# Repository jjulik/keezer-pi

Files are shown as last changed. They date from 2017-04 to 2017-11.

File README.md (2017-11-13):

# keezer-pi
Client/Server code for building a Keezer with a Raspberry Pi

## Complete setup guide
Download the raspbian lite image and put it on a micro SD card.

### Configure keyboard (and enable SSH)
`sudo raspi-config`

### Set the machine name
`sudo vi /etc/hosts`
`sudo vi /etc/hostname`

### Backup your wpa_supplicant
`sudo cp /etc/wpa_supplicant/wpa_supplicant.conf ~/wpa_supplicant.conf.bac`

### Connect to Wi-Fi
`wpa_passphrase "network_name" "passphrase" | sudo tee -a /etc/wpa_supplicant/wpa_supplicant.conf > /dev/null`

Then go edit the wpa_supplicant.conf to not have the password

`wpa_cli -i wlan0 reconfigure`

Check with

`ifconfig wlan0`

### Configure Wi-Fi to connect on boot
Set interface wlan0 in dhcpcd.conf

### Update Pi
`sudo apt-get update`
`sudo apt-get upgrade`

### Enable 1 wire interface
Edit /boot/config.txt

Add dtoverlay=w1-gpio

Then reboot the pi

`sudo shutdown -r -t 0`

### Install vim, git, and pip
`sudo apt-get install vim, git, pip`

### Clone the repo
`git clone https://github.com/jjulik/keezer-pi.git`

### Configure keezer-pi
Copy the keezer-pi.config.example to keezer-pi.config

Then edit the settings

### Install keezer-pi
`sudo ./install.sh`

Reboot the pi once more

`sudo shutdown -r -t 0`

And everything should be working correctly now

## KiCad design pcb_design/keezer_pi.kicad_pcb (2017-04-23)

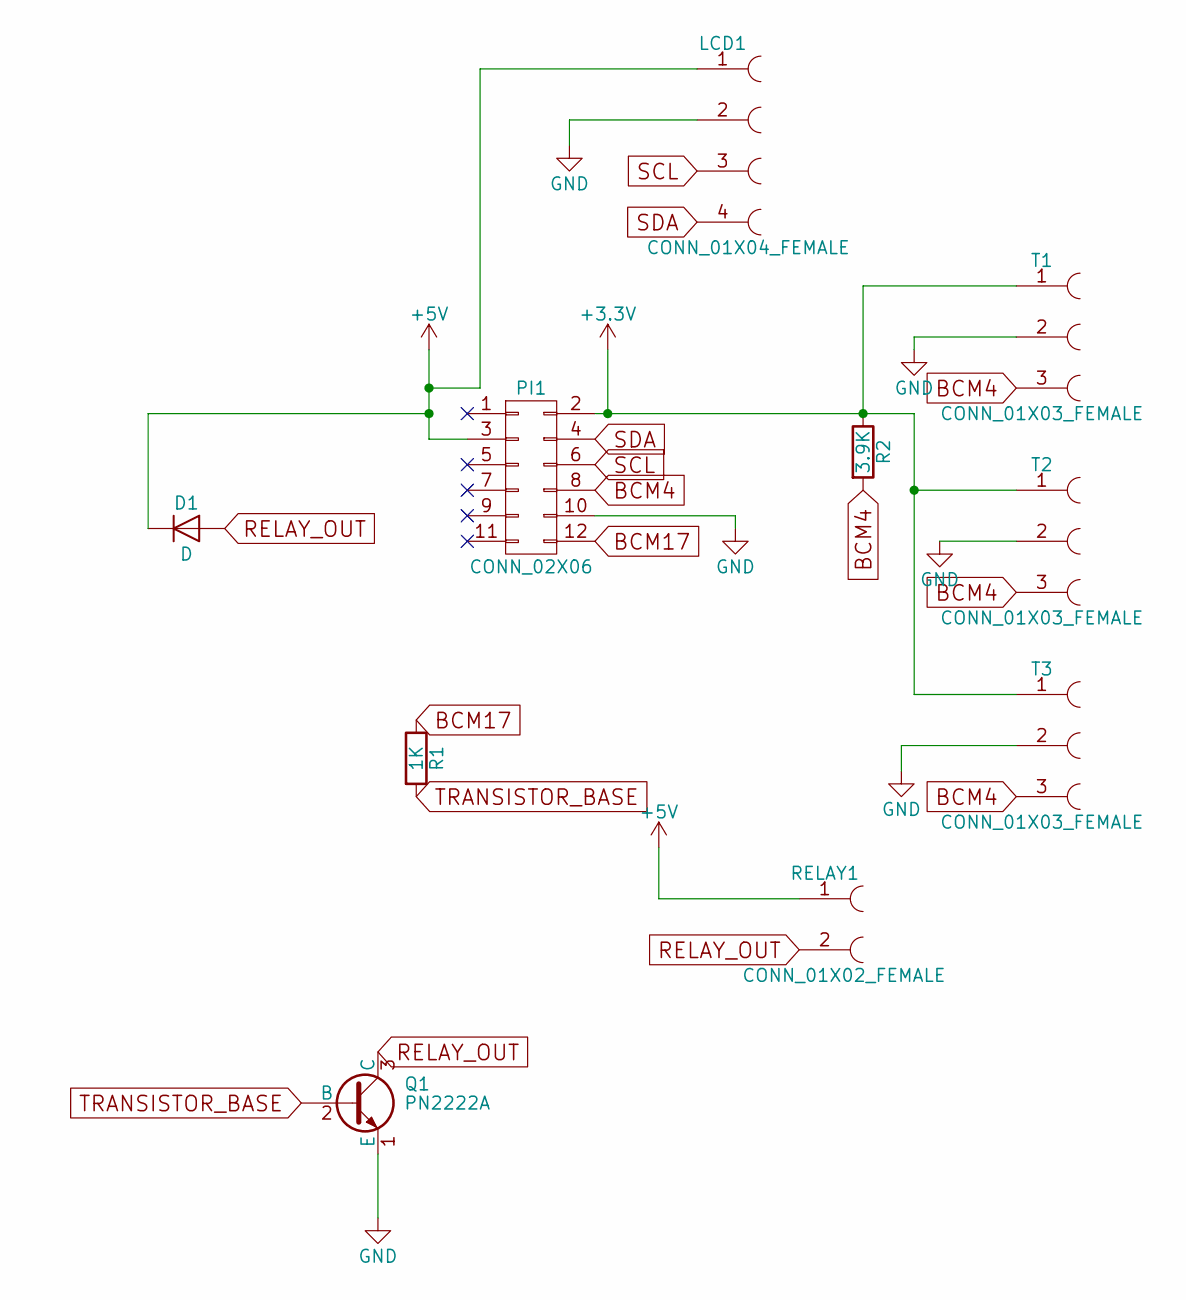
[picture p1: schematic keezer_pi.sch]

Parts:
D1: D; D_DO-41_SOD81_P7.62mm_Horizontal
LCD1: CONN_01X04_FEMALE; Socket_Strip_Angled_1x04_Pitch2.54mm
PI1: CONN_02X06; Pin_Header_Straight_2x06_Pitch2.54mm
Q1: PN2222A; TO-92_Inline_Wide
R1: 1K; R_Axial_DIN0207_L6.3mm_D2.5mm_P7.62mm_Horizontal
R2: 3.9K; R_Axial_DIN0207_L6.3mm_D2.5mm_P7.62mm_Horizontal
RELAY1: CONN_01X02_FEMALE; Socket_Strip_Angled_1x02_Pitch2.54mm
T1, T2, T3: CONN_01X03_FEMALE; Socket_Strip_Angled_1x03_Pitch2.54mm

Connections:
+3V3: PI1.2, R2.1, T1.1, T2.1, T3.1
+5V: D1.1 (K), LCD1.1, PI1.3, RELAY1.1
BCM4: PI1.8, R2.2, T1.3, T2.3, T3.3
BCM17: PI1.12, R1.1
GND: LCD1.2, PI1.10, Q1.1 (E), T1.2, T2.2, T3.2
RELAY_OUT: D1.2 (A), Q1.3 (C), RELAY1.2
SCL: LCD1.3, PI1.6
SDA: LCD1.4, PI1.4
TRANSISTOR_BASE: Q1.2 (B), R1.2

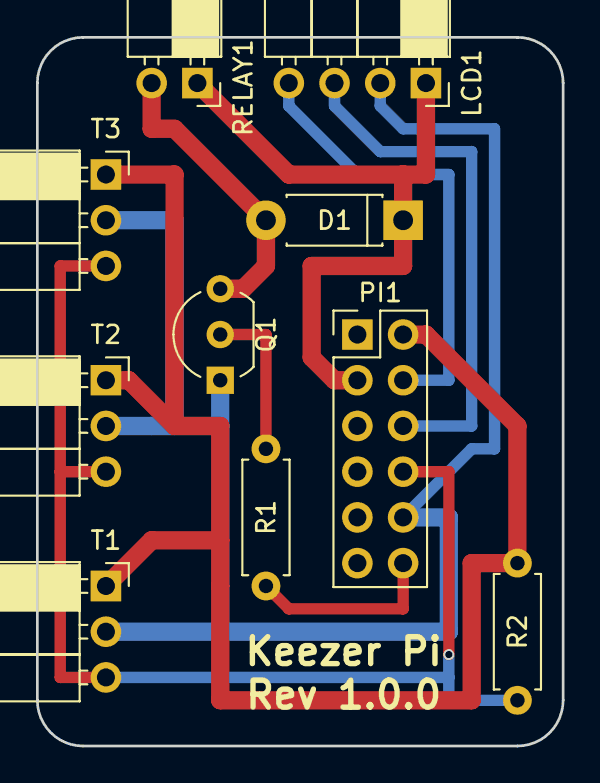
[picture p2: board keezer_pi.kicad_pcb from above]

Board: 2 copper layers, 29.2 x 39.4 mm, 10 parts (0 on the bottom side), 9 nets.

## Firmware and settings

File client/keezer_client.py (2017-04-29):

import os
import time
import json
import logging
import requests
import traceback
import time
import ConfigParser
import io
import threading
import RPi.GPIO as GPIO

# The primary sensor will be used for all sensor readings and determines
# whether we need to run the freezer.
# The secondary sensor will be used as a backup if the primary fails
# until the primary comes online again.
config_file = os.environ.get('KEEZER_CLIENT_SETTINGS')
if config_file is None:
	config_file = 'keezer_client.cfg'
with open(config_file, 'r') as f:
	config_text = f.read()
default_config = { 'secondary_temp': None, 'url': None, 'api_token': None, 'temperature': 40.0, 'deviation': 2.0, 'min_runtime': 60, 'cooldown': 300, 'fridge_name': 'fridgey' }
config = ConfigParser.SafeConfigParser(default_config, allow_no_value=True)
config.readfp(io.BytesIO(config_text))
primary_sensor_name = config.get('sensor', 'primary_temp')
secondary_sensor_name = config.get('sensor', 'secondary_temp')
relay_gpio_pin = config.getint('sensor', 'relay_pin')
server_url = config.get('server', 'url')
api_token = config.get('server', 'api_token')
desired_temperature = config.getfloat('fridge', 'temperature')
deviation = config.getfloat('fridge', 'deviation')
min_runtime = config.getint('fridge', 'min_runtime')
cooldown = config.getint('fridge', 'cooldown')
fridge_name = config.get('fridge', 'fridge_name')
max_temperature = desired_temperature + deviation

FORMAT = '%(asctime)-15s %(message)s'
logging.basicConfig(filename='keezer_client.log',level=logging.ERROR,format=FORMAT)
logger = logging.getLogger('keezer_client')

def post_async(url, headers, data):
	try:
		requests.post(url, headers=headers, data=json.dumps(data))
	except Exception:
		# don't log these errors
		# it could fill up the log fast if the server goes down
		return
		

def post_exception(formatted_exception):
	if server_url is None or api_token is None:
		return
	url = server_url + 'api/error'
	headers = { 'Authorization': api_token, 'Content-Type': 'application/json' }
	data = { 'time': time.time(), 'error': formatted_exception }
	# fire and forget
	postErrorThread = threading.Thread(target=post_async, args=(url,headers,data))
	postErrorThread.start()

def post_reading(reading):
	if server_url is None or api_token is None:
		return
	url = server_url + 'api/reading'
	headers = { 'Authorization': api_token, 'Content-Type': 'application/json' }
	data = { 'time': reading.time, 'reading': reading.reading, 'sensorDescription': reading.sensor_name }
	postReadingThread = threading.Thread(target=post_async, args=(url,headers,data))
	postReadingThread.start()

class Reading():
	def __init__(self, sensor_name, reading, reading_time):
		self.sensor_name = sensor_name
		self.reading = reading
		self.time = reading_time

# Inherit from dictionary for easy JSON serialization.
class Sensor(dict):
	def __init__(self, name):
		self.file_name = '/sys/bus/w1/devices/' + name + '/w1_slave' 
		dict.__init__(self, name=name, file_name=self.file_name)
		self.name = name

	def get_reading(self):
		try:
			f = open(self.file_name, 'r')
			lines = f.readlines()
			reading_time = time.time()
			equals_pos = lines[1].find('t=')
			if equals_pos != -1:
				raw_temp = float(lines[1][equals_pos+2:])
				#murica
				temp_f = (raw_temp / 1000.0) * 9.0 / 5.0 + 32.0
				return Reading(self.name, temp_f, reading_time)
		except Exception:
			logger.exception('Error reading sensor value for {0}'.format(self.name))
			post_exception(traceback.format_exc())
		return None

os.system('modprobe w1-gpio')
os.system('modprobe w1-therm')
primary_sensor = Sensor(primary_sensor_name)
secondary_sensor = None
if secondary_sensor_name is not None:
	secondary_sensor = Sensor(secondary_sensor_name)

try:
	# setup gpio pin for relay
	# we are using BCM numbering
	GPIO.setmode(GPIO.BCM)
	GPIO.setup(relay_gpio_pin, GPIO.OUT)
	GPIO.output(relay_gpio_pin, False)

	# keep track of when the fridge was last turned on or off
	# we don't want to be turning it on/off frequently
	fridge_turned_on = 0
	fridge_turned_off = 0
	fridge_enabled = False
	while True:
		primary_reading = primary_sensor.get_reading()
		secondary_reading = None
		if secondary_sensor is not None:
			secondary_reading = secondary_sensor.get_reading()
			
		if primary_reading is not None:
			post_reading(primary_reading)
		if secondary_reading is not None:
			post_reading(secondary_reading)
		
		reading_to_use = primary_reading
		if reading_to_use is None:
			reading_to_use = secondary_reading
		if reading_to_use is None and fridge_enabled:
			GPIO.output(relay_gpio_pin, False)
			fridge_enabled = False
			fridge_turned_off = time.time()
			power_reading = Reading(fridge_name, 0, fridge_turned_off)
			post_reading(power_reading)

		if reading_to_use is not None:
			if fridge_enabled:
				run_time = time.time() - fridge_turned_on
				if reading_to_use.reading < desired_temperature and run_time >= min_runtime:
					GPIO.output(relay_gpio_pin, False)
					fridge_enabled = False
					fridge_turned_off = time.time()
					power_reading = Reading(fridge_name, 0, fridge_turned_off)
					post_reading(power_reading)
			else:
				time_since_last_ran = time.time() - fridge_turned_off
				if reading_to_use.reading > max_temperature and time_since_last_ran >= cooldown:
					GPIO.output(relay_gpio_pin, True)
					fridge_enabled = True
					fridge_turned_on = time.time()
					power_reading = Reading(fridge_name, 1, fridge_turned_on)
					post_reading(power_reading)

		time.sleep(1)
except KeyboardInterrupt:
	GPIO.cleanup()
	exit(1)
except Exception:
	GPIO.cleanup()
	logger.exception('Fatal error in main loop')
	post_exception(traceback.format_exc())

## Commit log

2017-04-10 CLI method for getting active tokens, fix inserts by committing them
2017-04-10 CLI commands for adding/getting sensors
2017-04-15 Python script for testing temp sensors
2017-04-15 Add sample data from sensors
2017-04-15 Add sample config
2017-04-15 Fix sending errors to server from client
    [keezer_client.py]
2017-04-15 Async error upload so the main thread loop doesn't get blocked
    [keezer_client.py]
2017-04-15 Endpoint for sensor readings
2017-04-15 Log temperature readings from client and send to server
2017-04-16 Add logic for controlling fridge relay
2017-04-23 Fix error when no secondary sensor is attached
    [keezer_client.py]
2017-04-23 Add pcb design files; schematics are complete, but pcb design isn't
    [keezer-2.kicad_pcb, keezer.kicad_pcb, keezer.sch]
2017-04-23 Wire everything up in the pcb
    [keezer-2.kicad_pcb]
2017-04-23 Fix some silkscreen; fill bottom layer with ground zone
    [keezer-2.kicad_pcb]
2017-04-23 Add more silkscreen
    [keezer-2.kicad_pcb]
2017-04-23 Update pcb design to match OSH Park's minimum requirements
    [keezer-2.kicad_pcb]
2017-04-23 Update pcb file names, remove duplicate files
    [keezer.kicad_pcb, keezer.sch, keezer_pi.kicad_pcb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]
2017-04-27 Adding temperature graphs for server
2017-04-29 Server side power logging
2017-04-29 Send power readings from client
2017-04-29 Different chart labels for temperature and power sensors
2017-04-29 Cleaning up power charts
2017-11-13 Update example config to use pin 17, which matches the pcb design
